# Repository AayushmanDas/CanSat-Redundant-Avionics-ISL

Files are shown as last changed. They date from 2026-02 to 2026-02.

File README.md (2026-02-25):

# CanSat-Redundant-Avionics-ISL

**1. Project Summary:**

The design and development of the CanSat successfully demonstrated the
integration of dual-modular redundancy within a constrained 160mm airframe.
By utilizing a parallel electronic architecture and a mechanically redundant
slotted-latch system, the mission profile achieves a significantly higher reliability
coefficient compared to single-MCU designs.

**2. Key Achievements:**

● System Independence: Successfully isolated Primary and Secondary
systems across independent power rails and processing units.

● Mechanical Innovation: Developed a single-fault tolerant parachute
release mechanism that eliminates the risk of servo-jamming through a
slotted pin interface.

● Mass Efficiency: Optimized the internal structural integrity using
honeycomb weight-reduction pocketing, ensuring the 88mm PCB
assembly remains flight-worthy while minimizing total mass.

● Prototyping Proficiency: Successfully transitioned from breadboard-level
concepts to bare ESP32-WROOM module integration and advanced 3D
CAD modeling.

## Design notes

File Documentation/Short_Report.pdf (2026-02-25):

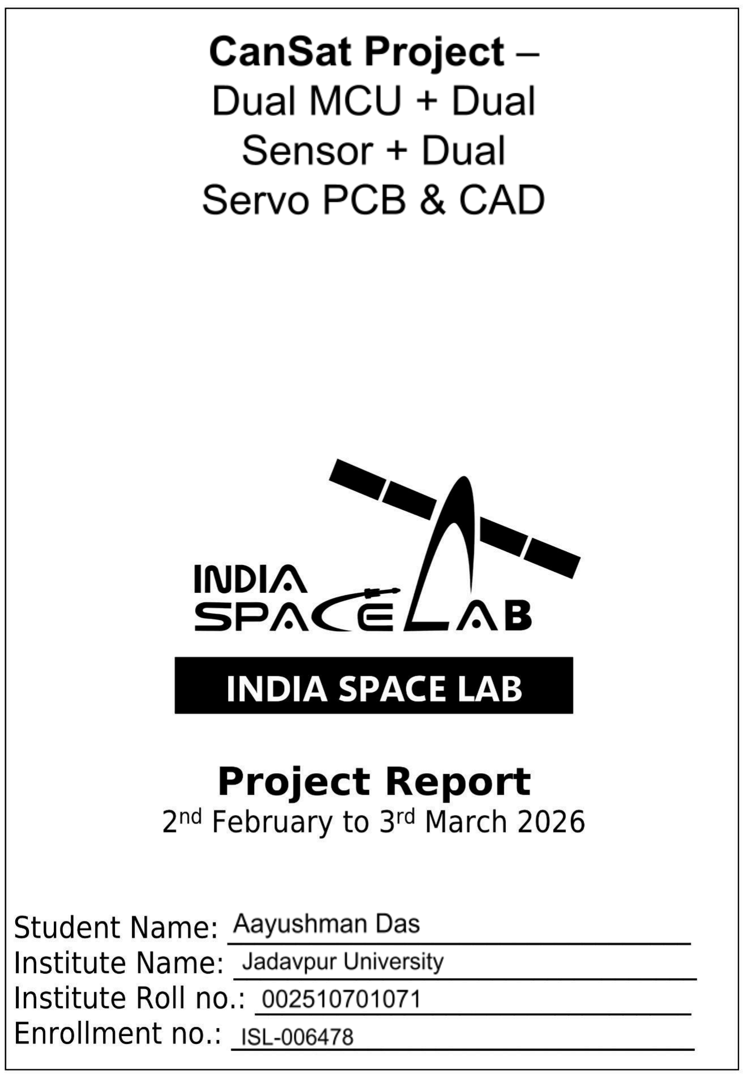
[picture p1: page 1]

# Electronic System Design & PCB Layout

## 1. Hardware Specifications:

Component | Specification | Redundancy Role
Microcontrollers | 2x ESP32-WROOM-32 | Primary & Secondary (Independent)
Board Diameter | 88 mm (Circular) | Physical trace isolation
Power Regulation | LM7805 & MCP1700 | Independent power rails
Sensors (IMU) | 2x MPU6050

Orientation & Stability
tracking
Sensors (Altimeter) | 2x BMP280

Dual-pressure/altitude
monitoring

Connectors JST-PH 2.0 & Pin Headers

Secure vibration-resistant interface

## 2. PCB Layout Strategy:

To maximize mission reliability, the PCB was designed using a symmetrical dual-modular approach.

- Spatial Separation: By expanding the board to 88mm, we achieved a "buffer zone" between the Primary (System A) and Secondary (System B) routing. This minimizes the risk of a single physical impact or localized thermal event damaging both processing units.
- Module-Level Integration: Rather than using bulky development boards, bare ESP32-WROOM modules were utilized. This reduces the vertical profile of the PCB, creating a dedicated 30mm clearance zone for battery storage and cable management within the CanSat body.
- Dual-Rail Power Architecture: The system uses two distinct voltage regulators. The Primary system is backed by a robust LM7805 for heat dissipation, while the Secondary system utilizes an MCP1700 for high-efficiency low-dropout regulation, ensuring the backup system remains active even if the battery voltage drops.

## 3. Trace and Signal Integrity:

Power Trace Width: Critical power delivery traces and most important traces were widened to 24mil to ensure reliability under the peak current draws of the dual ESP32 Wi-Fi/Bluetooth stacks and servo actuation.

Independent I2C Buses: System A and System B utilize separate I2C bus lines, preventing a sensor hang-up on one system from "locking" the communication lines of the other.

# CAD Design & Structural Integration

## 1. Structural Assembly Overview:

Section | Vertical Zone | Primary Function
Parachute Bay | 130mm – 160mm

Housing for recovery system and hinged lid.

Actuation Zone 110mm – 130mm

Dual SG90 servos and redundant sliding latch.

Electronics Bay 30mm – 110mm

Redundant PCB assembly and sensor mounts.

Power & Base | 0mm – 30mm

Battery storage, sensor vents, and structural base.

## 2. Mechanical Redundancy Logic:

The structural design prioritizes the Single-Fault Tolerance of the parachute deployment:

- Slotted Sliding Pin: The latch uses a "slotted" mechanical interface. This allows either the Primary or Secondary servo to pull the locking bolt without being hindered by the mechanical resistance of the other (potentially failed) servo.
- Internal Honeycomb Shelving: To comply with aerospace mass constraints, internal mounting shelves feature circular cutouts. This reduces overall mass by approximately 15% while maintaining the rigidity required to withstand launch vibrations.
- Modular Assembly: The CanSat uses a modular approach where the Bottom Cap is a separate body from the main cylinder. This allows the 88mm PCB to be inserted from the bottom and secured against internal standoffs, simplifying maintenance and pre-flight checks.

## 3. Environmental Sensing Integration:

Static Vents: Four 3mm ventilation ports are positioned circumferentially around the Electronics Bay. These ensure that the internal BMP280 sensors are exposed to ambient atmospheric pressure for accurate altitude triggering.

# Software Logic & Redundancy Strategy

## 1. Independent Parallel Logic Flow:

The CanSat operates on a "Dual-Active" logic. Both the Primary and Secondary MCUs run identical mission firmware but operate on independent sensor data and power rails.

Flight Phase | Primary MCU Action | Secondary MCU Action
Launch | Detects high-G acceleration; arms latch.
Apogee | Monitors pressure drop to detect the peak.
Descent | Reaches 300m threshold; pulls pin.
Recovery | Enters beacon mode (Buzzer/LED).

Detects high-G
acceleration; arms latch.

Monitors pressure drop to
detect the peak.

Reaches 300m threshold;
pulls pin.

Enters beacon mode
(Buzzer/LED).

## 2. Fail-Safe Deployment Scenarios:

To ensure the parachute deploys even in the event of a partial system failure, the following logic is implemented:

- Scenario A: Nominal Operation- Both MCUs reach the target altitude (e.g., 300m) and actuate their respective servos. Because of the slotted linkage in your CAD design, the two servos move the sliding pin simultaneously without mechanical conflict.
- Scenario B: Primary System Failure- If the Primary MCU loses power or the BMP280 fails, the Secondary MCU, operating on its own independent power rail, detects the threshold. It pulls the sliding pin via the slotted linkage, successfully deploying the parachute.
- Scenario C: Sensor "Ghosting" prevention- Each MCU uses a 3-point moving average filter on the altitude data. This prevents a single noisy sensor reading (common in high-vibration launches) from triggering a premature deployment.

## 3. State Machine Overview:

The software is structured as a Finite State Machine (FSM) to prevent logic loops:

1. IDLE: Waiting for launch (low power mode).
2. ASCENT: High-speed data logging (BMP280 + MPU6050).
3. APOGEE_CHECK: Identifying the moment of zero vertical velocity.
4. DEPLOYMENT: Actuating the SG90 servos.
5. LANDED: Transmitting GPS/Beacon coordinates for recovery.

# Conclusion

## 1. Project Summary:

The design and development of the CanSat successfully demonstrated the integration of dual-modular redundancy within a constrained 160mm airframe. By utilizing a parallel electronic architecture and a mechanically redundant slotted-latch system, the mission profile achieves a significantly higher reliability coefficient compared to single-MCU designs.

## 2. Key Achievements:

- System Independence: Successfully isolated Primary and Secondary systems across independent power rails and processing units.
- Mechanical Innovation: Developed a single-fault tolerant parachute release mechanism that eliminates the risk of servo-jamming through a slotted pin interface.
- Mass Efficiency: Optimized the internal structural integrity using honeycomb weight-reduction pocketing, ensuring the 88mm PCB assembly remains flight-worthy while minimizing total mass.
- Prototyping Proficiency: Successfully transitioned from breadboard-level concepts to bare ESP32-WROOM module integration and advanced 3D CAD modeling.

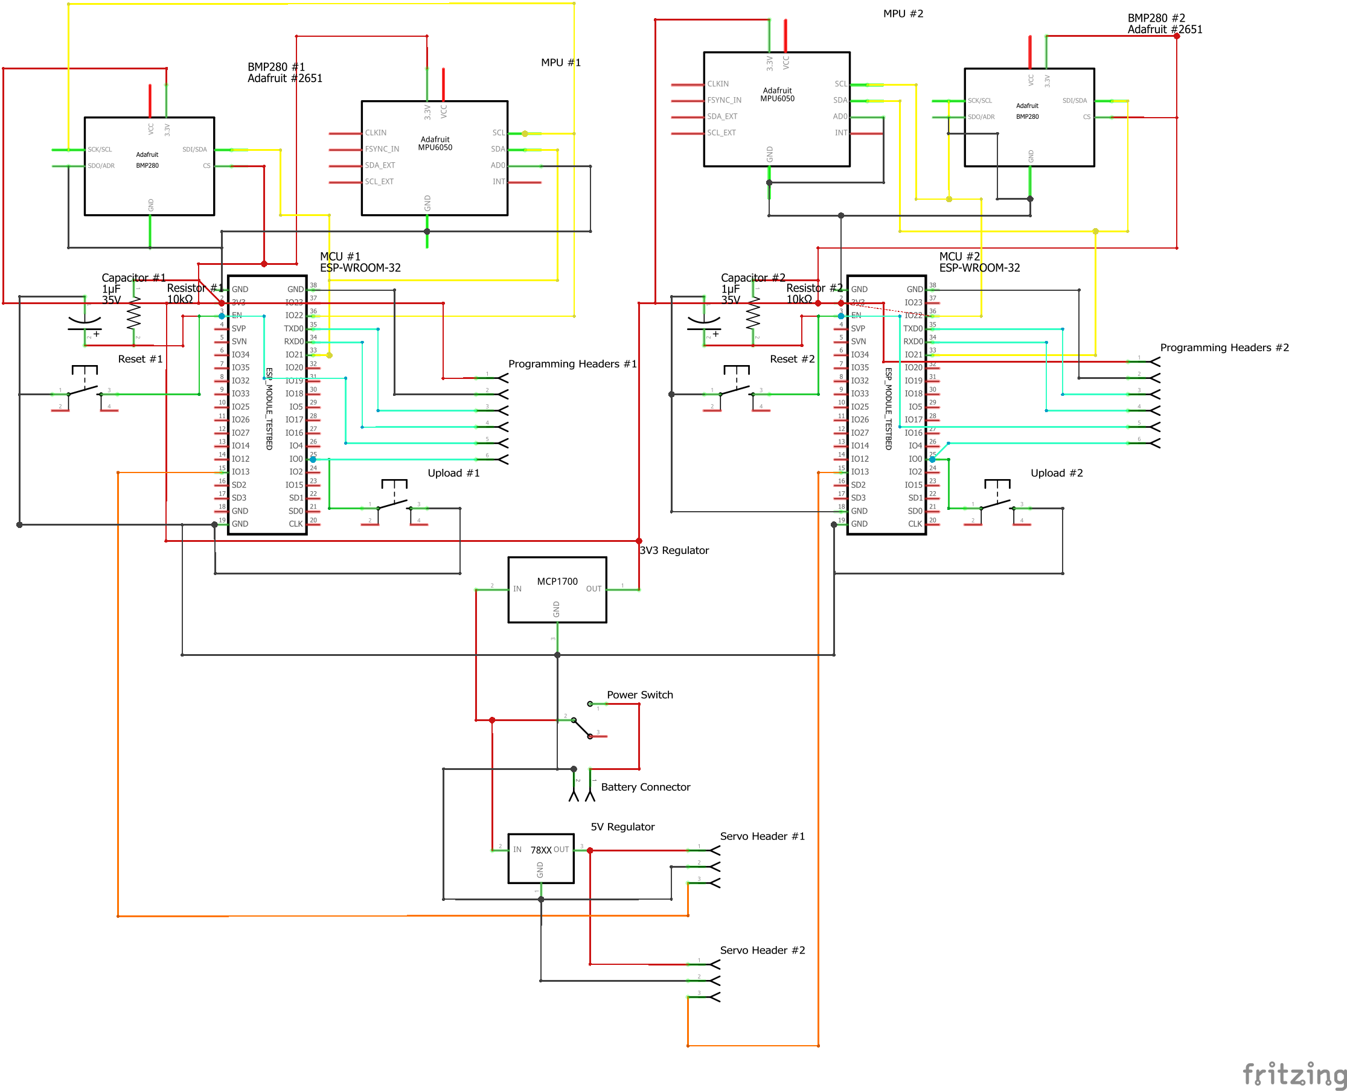
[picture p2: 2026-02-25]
PCB_Design/CanSat_schem.png

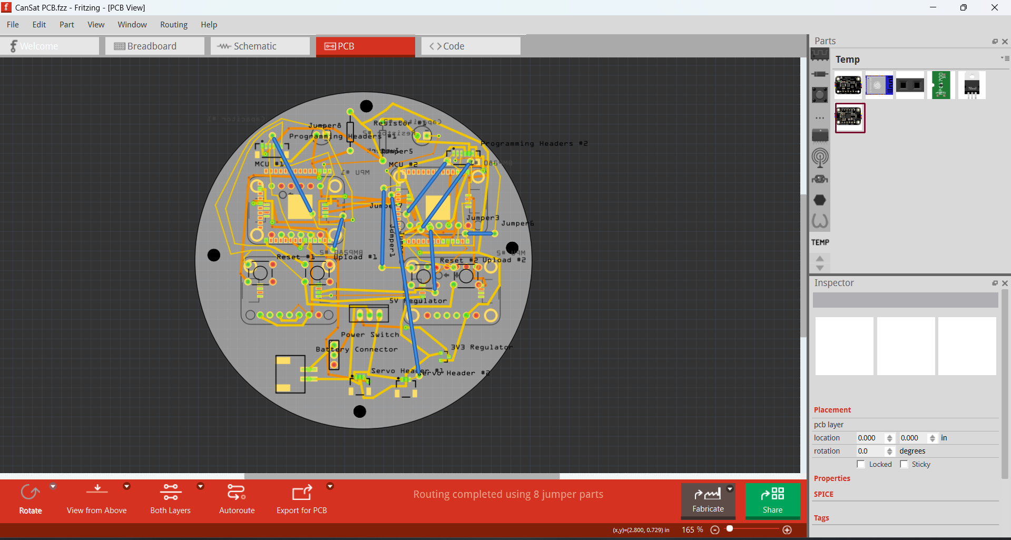
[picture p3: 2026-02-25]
PCB_Design/CanSat_3Dpcb_screenshot.png

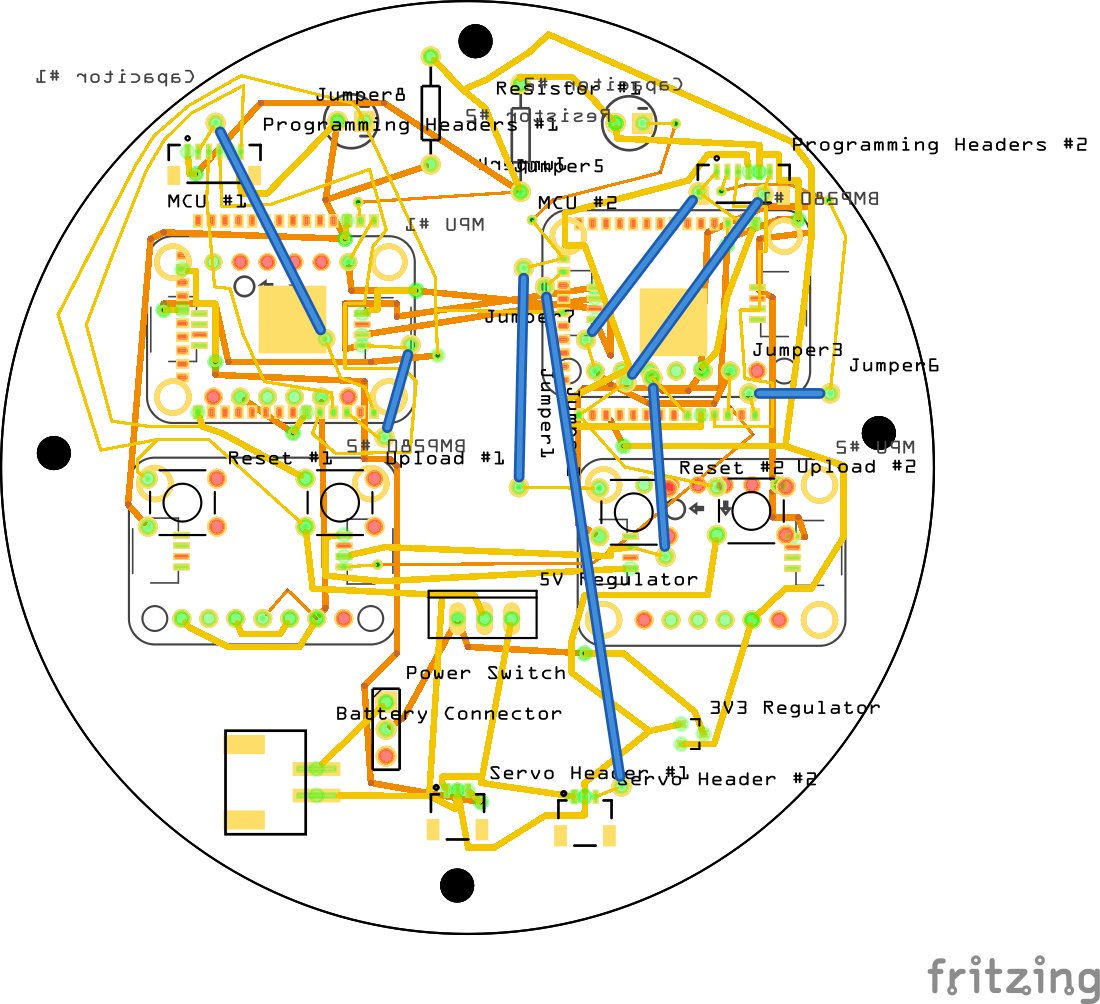
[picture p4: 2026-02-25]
PCB_Design/CanSat_pcb.png

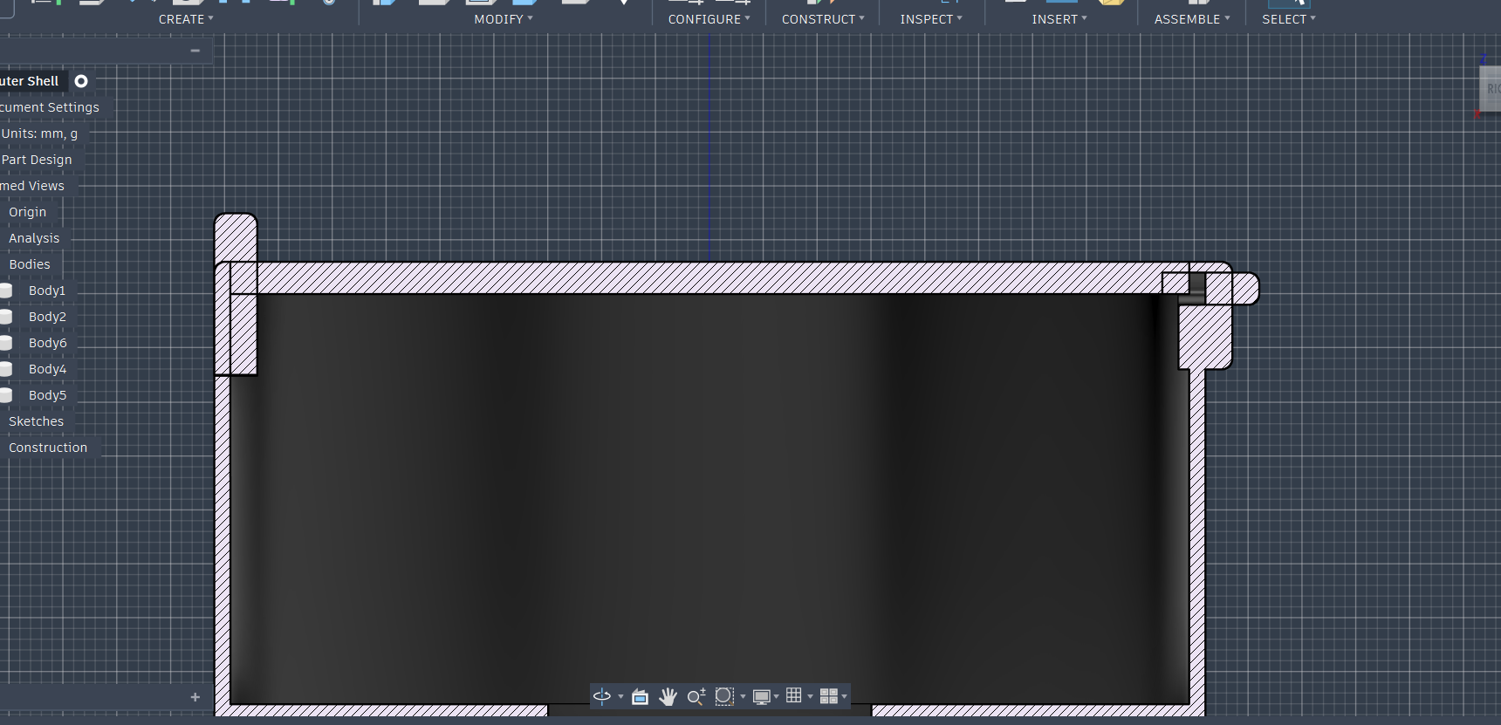
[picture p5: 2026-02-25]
CAD_Model/Close up of Sliding Pin Lock Mechanism.png

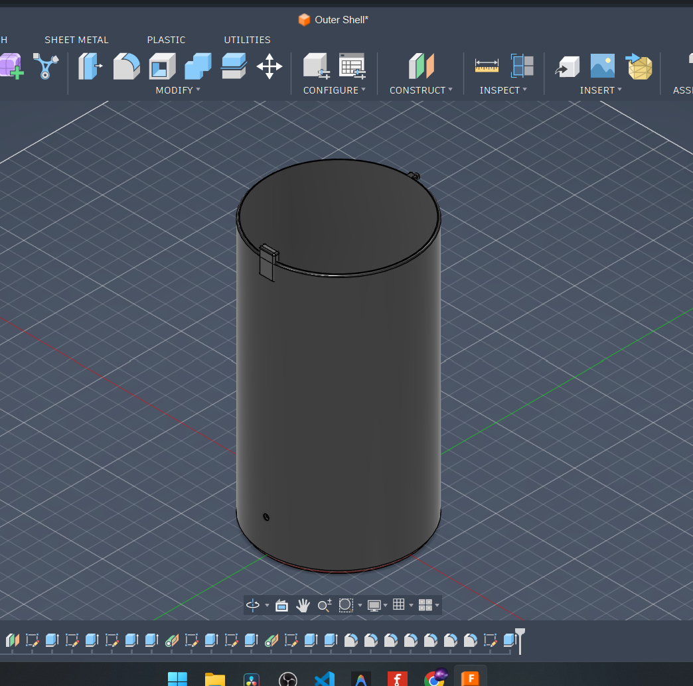
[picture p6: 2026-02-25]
CAD_Model/Isometric View of the CanSat Body.png

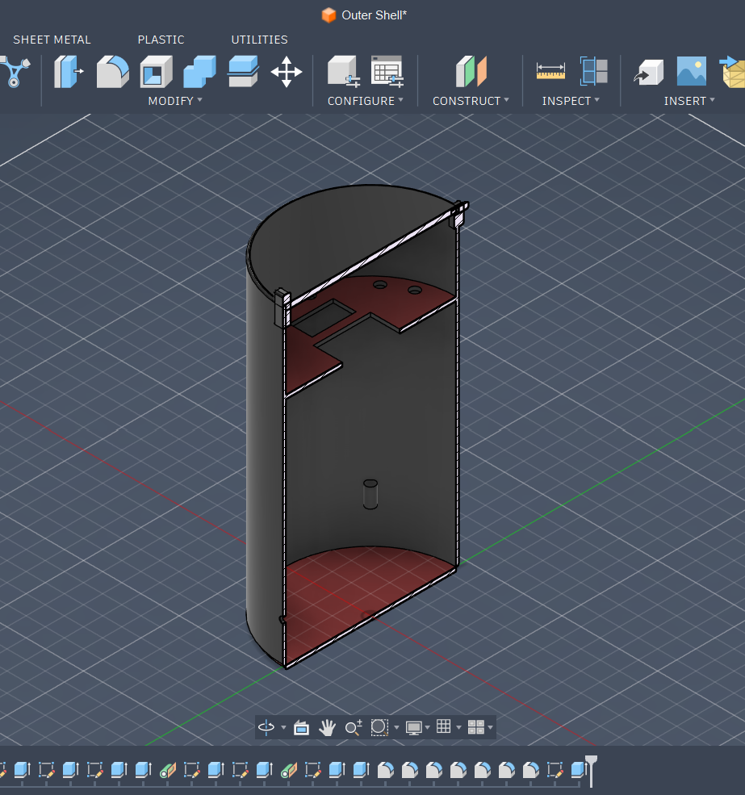
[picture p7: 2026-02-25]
CAD_Model/Section Analysis View of the CanSat Body.png

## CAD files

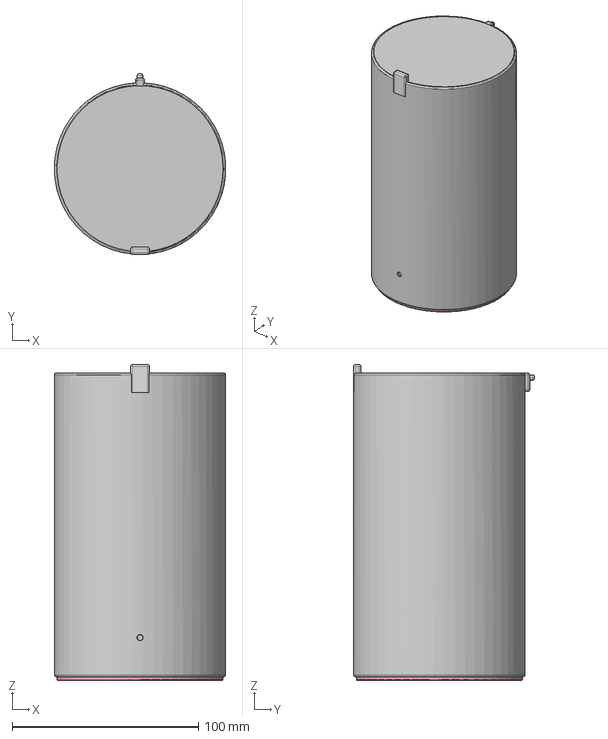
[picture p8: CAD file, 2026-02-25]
CAD_Model/Aayushman_Das_CanSat_CAD.step
92.0 x 97.0 x 169.5 mm

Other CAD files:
CAD_Model/Aayushman_Das_CanSat_CAD_Source.f3d

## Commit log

2026-02-25 Added all PCB files
    [CanSat_PCB_Source.fzz]
2026-02-25 Added all the Gerber Files
    [CanSat PCB_contour.gm1, CanSat PCB_copperBottom.gbl, CanSat PCB_copperTop.gtl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]
2026-02-25 Added all CAD files
    [Aayushman_Das_CanSat_CAD.step, Aayushman_Das_CanSat_CAD_Source.f3d]
